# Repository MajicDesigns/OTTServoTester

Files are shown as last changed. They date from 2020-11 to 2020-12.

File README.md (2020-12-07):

# Over The Top (OTT) Servo Tester

Arduino sketch to test and calibrate micro (RC) servos.

The application can work in Manual, Sweep, Receiver Check and ESC setup modes.

## Hardware Requirements

- Arduino processor (Pro Mini, but any processor should work)
- Hitachi 1602 LCD display with IIC backpack
- Rotary encoder with built-in momentary-on switch
- Additional momentary-on switch

If you like and use this code please consider making a small donation using [PayPal](https://paypal.me/MajicDesigns/4USD)

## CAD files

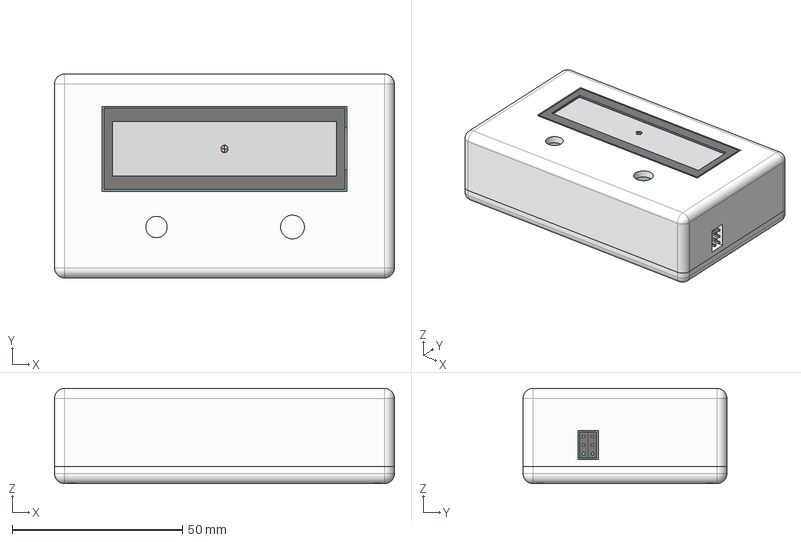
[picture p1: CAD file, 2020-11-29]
Fusion360/OTT Servo Tester Enclosure.step
100.0 x 60.0 x 28.0 mm
Cover
LCD PCB
LCD Bezel
LCD Glass
PCB Connector
I2C PCB
I2C Connectors
Cap1
Reset Body
CPU
Reset Switch
Tx
Cap2
PCB
Header
PCB (1)
Header (1)
PCB (2)

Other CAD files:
Fusion360/OTT Servo Tester Enclosure.f3z

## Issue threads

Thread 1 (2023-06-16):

OTTServoTester with LCD Keypad Shield

freetoair, 2023-06-16:
Hi Marco, I tried to modify your excellent project to work with "LCD Keypad Shield" but without success.
The part with the parallel LCD display works correctly, but the control of the analog keys is a big problem for me.
If there is some way to do it without a lot of involvement, I think it would mean a lot to many who would be happy to use this tester. If it means anything, I can upload my modified Sketch.

regards,  freetoair.

MajicDesigns, 2023-06-17:
Use the analog keys tester example in the UISwitch library to work out the analog values for the switches on your keypad shield. The substitute these values for those in the OTTtester code.

freetoair, 2023-06-17:
Yes, that's exactly what I tried to do, but as you can see from my program in debug mode when selecting in the "setup" menu, it's as if some key was pressed, but it wasn't!
Here I am sending the variant that I tried.
[OTTServoTester_LCDkeySheld.zip](https://github.com/MajicDesigns/OTTServoTester/files/11778641/OTTServoTester_LCDkeySheld.zip)

MajicDesigns, 2023-07-02:
"as you can see from my program in debug mode" - not really, I can't see anything that is debug output.

One area that often causes you problem is if you are trying to power the servos from the Arduino board. As soon as the servos start to move they will cause a dip on the voltage on the board and noise in the electonic components power supply which makes them behave erratically.

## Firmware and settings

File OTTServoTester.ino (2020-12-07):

/*
Over The Top (OTT) Servo Tester
===============================

Hardware Requirements
---------------------
* Arduino processor (Pro Mini, but any processor should work)
* Hitachi 1602 LCD display with IIC backpack
* Rotary encoder with built-in momentary-on switch
* Additional momentary-on switch

I/O Mapping - Arduino Pro Mini
------------------------------
+---+-----------------------+-------------------+
|Pin| Usage                 | Defined           |
+---+-----------------------+-------------------+
| 00| USB Serial            | N/A               |
| 01| USB Serial            | N/A               |
| 02| Servo Output A        | SERVO_PIN[0]      |
| 03| Servo Output B        | SERVO_PIN[1]      |
| 04| Servo Output C        | SERVO_PIN[2]      |
| 05| Servo Output D        | SERVO_PIN[3]      |
| 06| Servo Output E        | SERVO_PIN[4]      |
| 07| Servo Output F        | SERVO_PIN[5]      |
| 08|                       |                   |
| 09|                       |                   |
| 10|                       |                   |
| 11| Receiver Signal Pin   | RCV_PIN           |
| 12|                       |                   |
| 13|                       |                   |
| A0| Menu encoder B        | MENU_ENC_B        |
| A1| Menu encoder A        | MENU_ENC_A        |
| A2| Menu encoder select   | MENU_SEL          |
| A3| Run switch            | MENU_RUN          |
| A4| IIC SDA               | LCD_SDA           |
| A5| IID SCL               | LCD_SCL           |
| A6|                       |                   |
| A7|                       |                   |
+---+-----------------------+-------------------+

Summary
-------
The Application operates in one of three modes, cycled through a double press of the encoder switch.

Manual: Manual mode is shown by 'Man' in the top right of the display. Moving the encoder moves all
        the servos in unison. A single press of the Run switch resets all the servos to their home
        position, as configured in the associated profile.

Sweep:  Sweep mode display shows the same information as Manual mode display, with 'Swp' in the top right.
        In this mode the servos are swept between their associated profile start and end positions using
        the defined sweep profile (Linear, Sine or Square) and timing parameters. The sweep is toggled
        on/off by a single press of the Run switch.

Rcv Check: Rcv Check displays the signal characteristics from a servo controller connected to the RCV_PIN
        input. Signal high and low durations are displayed in real time.

ESC Setup: ESC (Electronic Speed Controller) setup allows the togglong of one of the outputs between high 
         and low as is normally required for ESC setup through a receiver. The ESC will be emitting tones 
         to guide you through a menu of options according to the specifics of the ESC (see appropriate ESC
         documentation). The output for the ESC can be selected by turning the rotary encoder.

The application code is configured to allow for up to MAX_SERVO servos to be attached for testing.
The actual number of active servos is set by the NUM_SERVO (<= MAX_SERVO) constant. Each of the 
Servo outputs (labeled Output A through F) is associated with a servo profile. 

Each servo has associated a profile defining the travel timing limits for the servo. Up to MAX_PROFILE
profiles are allowed for. The actual number of profiles is set by the NUM_PROFILE constant. Note the 
variable selProfile needs to be manually adjusted for menu selections if the value of NUM_PROFILE is 
changed.

The servo profiles are configurable and define the minimum and maximum values for the servo sweep 
(in microseconds), the percentage of range to set as the 'mid-point' value, the type of sweep testing 
(Linear, Sine or Square patterns), the sweep duration and the pause between sweeps. By default three 
profiles are created with range 1000 to 2000 microseconds and 'mid' point (or 'home') values at 50%, 
0% and 100% for profiles 1, 2 and 3 respectively. An output with no associated profile is considered 
as 'disabled' and will not receive control signals.

The user interface (UI) is implemented using the rotary encoder and a separate tact switch (Run switch).
In general the UI navigation operates as follows:
 * Cycle between modes by double pressing the encoder switch.
 * The Run Switch is used to run/stop execution in the mode (if applicable). A long press of the run 
   switch will immediately return the application to Manual mode.
 * The Configuration Menu only uses the encoder, accessed from Manual mode using a long press of the 
   encoder switch.
     - The top line of the display is the menu/submenu name or the value being edited.
     - Below the title, Menu Selections are displayed inside angled brackets ("<" and ">").
     - Editable values are displayed inside square brackets ("[" and "]").
     - Menu options are scrolled by turning the encoder
     - Menu options are selected by pressing the encoder switch.
     - Configuration item values are changed up/down by turning the encoder switch
     - Configuration items are confirmed by pressing the encoder switch.
     - Aborting the current menu level (menu selection or value editing) is done using a long press.
     
The application stores all its configuration information in EEPROM so that it is retained between 
processor resets. Configuration items include
* Display parameters for splash screen, menu timeouts and auto paging
* Safety limits on servo timing values
* Profile definitions (as described above)
* Assignment of profile to servo

Library Dependencies
--------------------
- Rotary encoder (MD_REncoder) at https://github.com/MajicDesigns/MD_REncoder or Arduino IDE Library Manager
- Menu switches (MD_UISwitch) at https://github.com/MajicDesigns/MD_UISwitch or Arduino IDE Library Manager
- LCD Menu (MD_Menu) at https://github.com/MajicDesigns/MD_Menu or Arduino IDE Librarey Manager
- LCD Manager (HD44780) at https://github.com/duinoWitchery/hd44780 or Arduino IDE Library Manager

Version History
---------------
Dec 2020 v1.1.0
- Added ESC setup mode

Nov 2020 v1.0.0
- First Release

Copyright and Licensing
-----------------------
Copyright (C) 2020 Marco Colli. All rights reserved.

This is free software; you can redistribute it and/or
modify it under the terms of the GNU Lesser General Public
License as published by the Free Software Foundation; either
version 2.1 of the License, or (at your option) any later version.

This library is distributed in the hope that it will be useful,
but WITHOUT ANY WARRANTY; without even the implied warranty of
MERCHANTABILITY or FITNESS FOR A PARTICULAR PURPOSE. See the GNU
Lesser General Public License for more details.

You should have received a copy of the GNU Lesser General Public
License along with this software; if not, write to the Free Software
Foundation, Inc., 51 Franklin St, Fifth Floor, Boston, MA 02110-1301 USA
*/
#include <EEPROM.h>
#include <Servo.h>

#include <Wire.h>
#include <hd44780.h>
#include <hd44780ioClass/hd44780_I2Cexp.h>

#include <MD_REncoder.h>
#include <MD_UISwitch.h>
#include <MD_Menu.h>

// Application options
const uint8_t MAX_SERVO = 6;   // Maximum number of servos allowed for. NUM_SERVO sets the actual number (below).

#define DEBUG   0  // enable debugging output
#define USE_RCV 1  // enable the Receiver functionality
#define USE_ESC 1  // enable the ESC setup functionality

#if DEBUG
#define PRINT(s, n)  do { Serial.print(F(s)); Serial.print(n); } while (false);
#define PRINTS(s)    do { Serial.print(F(s)); } while (false);
#define PRINTX(s, x)  do { Serial.print(F(s)); Serial.print(F("x")); Serial.print(x, HEX); }  while (false);
#else
#define PRINT(s, n)
#define PRINTS(s)
#define PRINTX(s, x)
#endif // DEBUG

//----------------------------------------------------------
// Miscellaneous definitions/variables
#define APP_NAME "OTT Servo Tester"
#define APP_VER  "v1.1.0"

typedef const char PROGMEM message_t;	// pointer to flash memory string

enum:uint8_t 
{ 
  RUN_MANUAL_INIT, RUN_MANUAL,
  RUN_SWEEP_INIT, RUN_SWEEP_WAITING, RUN_SWEEP,
  RUN_RCHECK_INIT, RUN_RCHECK, RUN_RCHECK_PAUSE,
  RUN_ESC_INIT, RUN_ESC,
  RUN_MENU_INIT, RUN_MENU
} runMode = RUN_MANUAL_INIT;
bool dataChanged = true;    // flag for new data to display

//----------------------------------------------------------
// Servo Hardware
const uint16_t SERVO_UPDATE_FREQ = 50;       // standard servo update frequency in Hz
const uint16_t SERVO_LOWER_HARDLIMIT = 500;  // servo abs lower hard limit
const uint16_t SERVO_UPPER_HARDLIMIT = 2500; // servo abs upper hard limit

const uint8_t NUM_SERVO = MAX_SERVO;         // number of physical servos (can be [1..MAX_SERVO-1])
const uint8_t SERVO_PIN[MAX_SERVO] = { 2, 3, 4, 5, 6, 7 };  // only NUM_SERVO pins are relevant

const uint8_t NUM_PROFILE = 3;       // number of available profiles - also adjust selProfile below
message_t selProfile[] = "-|1|2|3";  // menu selection data for profile - adjust to allow NUM_PROFILE selections

message_t selSweepType[] = "Lin|Sin|Sqr";  // menu selection data - for sweep type in profile
const uint8_t SWP_LINEAR = 0;   // index 0
const uint8_t SWP_SINE = 1;     // index 1
const uint8_t SWP_SQUARE = 2;   // index 2

Servo servo[NUM_SERVO];

//----------------------------------------------------------
// Receiver Signal Test
#if USE_RCV
const uint8_t RCV_PIN = 11;
const uint32_t RCV_PAUSE_TIME = 500; // milliseconds pause between readings

struct
{
  uint32_t timeSig;  // signal duration measured (microseconds)
  uint32_t timeGap;  // space duration measured (microseconds)
  uint32_t timePause;    // receiver pause timer counter (milliseconds)
} rcvCheckData;
#endif

//----------------------------------------------------------
// ESC Setup
#if USE_ESC
uint8_t escOutput;     // output used for ESC setup
bool    escState;      // currently high or low
#endif

//----------------------------------------------------------
// Menu Rotary Encoder Interface I/O
const uint8_t MENU_SEL = A2;   // Selection switch on encoder
const uint8_t MENU_RUN = A3;   // Run start/stop
const uint8_t MENU_ENC_A = A1; // Encode Channel A
const uint8_t MENU_ENC_B = A0; // Encoder Channel B

MD_REncoder encMenu(MENU_ENC_A, MENU_ENC_B);
MD_UISwitch_Digital swMenuSel(MENU_SEL);
MD_UISwitch_Digital swMenuRun(MENU_RUN);
uint8_t displayPageBase = 0;   // base index for servo disaply page

//----------------------------------------------------------
// LCD Display definitions (2 wire display interface)
#define LCD_PRINT(c, r, s) do { lcd.setCursor(c,r); lcd.print(s); } while (false);
#define LCD_WRITE(c, r, s) do { lcd.setCursor(c,r); lcd.write(s); } while (false);

const uint8_t LCD_ROWS = 2;
const uint8_t LCD_COLS = 16;

const uint8_t LCD_SCL = A5;
const uint8_t LCD_SDA = A4;

hd44780_I2Cexp lcd;

//----------------------------------------------------------
// Auto paging management definitions
const uint32_t PAGE_TIME = 2000;   // page displayed time in ms for auto paging
uint32_t timerPage;     // keeping track of millis() time

//----------------------------------------------------------
// Configuration Information handling
//
// - Config info is made up of common data and additional data per channel.
// - This config info is saved at the start of EEPROM memory (address EEPROM_ADDR).
//
// Any changes to data structure need to be reflected in the static initializers in 
// the reset() method.
//
class cAppConfig
{
public:
  // Data fields --------------------------------
  struct
  {
    uint8_t signature[2];

    // UI options
    uint8_t		tmMenu;			// menu timeout in seconds
    uint8_t		tmSplash;		// splash screen display time in seconds
    bool      autoPage;   // automatically page through the main display

    // Safety limits for signal setting
    uint16_t  limLow;     // low limit in milliseconds
    uint16_t  limHigh;    // high limit in milliseconds

    // Servo Signal options
    struct 
    {
      bool enabled;       // true if servo is enabled for output
      uint8_t profileId;  // configured profile to use
    } servo[MAX_SERVO];
    
    // Profile information
    struct 
    {
      uint16_t low;        // setting for 0% of range
      uint16_t high;       // setting for 100% of range
      uint8_t  home;       // setting for home position as percentage
      uint8_t  sweepType;  // sweep type
      uint16_t sweepTime;  // duration in milliseconds for one low->high or high->low sweep
      uint16_t sweepPause; // pause between sweep movements in milliseconds
    } profile[NUM_PROFILE];

  } data;

  // Methods ------------------------------------
  cAppConfig(uint16_t eepromBase = 0) : _eepromBase(eepromBase) {}

  void reset(void)
  {
    PRINTS("\nConfig Reset");

    data.signature[0] = EEPROM_SIG[0];
    data.signature[1] = EEPROM_SIG[1];

    // Global config presets 
    data.tmMenu = 4;      // menu timeout in seconds
    data.tmSplash = 2;    // slapsh screen timeout in seconds

    // Safety limits 
    data.limLow = SERVO_LOWER_HARDLIMIT;    // low limit in microseconds
    data.limHigh = SERVO_UPPER_HARDLIMIT;   // high limit in microseconds
    data.autoPage = true;                   // default to autopaging

    // Servo information
    for (uint8_t i = 0; i < MAX_SERVO; i++)
    {
      data.servo[i].enabled = true;
      data.servo[i].profileId = 0;    // all use the same profile initially
    }

    // Profiles information
    for (uint8_t i = 0; i < NUM_PROFILE; i++)
    {
      data.profile[i].low = 1000;   // in microseconds
      data.profile[i].high = 2000;  // in microseconds
      data.profile[i].home = 0;     // percentage of range
      data.profile[i].sweepType = SWP_LINEAR; // one of the 
      data.profile[i].sweepTime = 2000;  // in milliseconds
      data.profile[i].sweepPause = 200;  // in milliseconds
    }
    data.profile[0].home = 50;    // set specific percentage value
    data.profile[1].home = 0;
    data.profile[2].home = 100;
  }

  void begin(void)
  {
    if (!load())
    {
      reset();
      save();
    }
  }

  void save(void) 
  { 
    PRINTS("\nConfig Save");
    EEPROM.put(_eepromBase, data);
  }
  
  bool load(void) 
  {
    PRINTS("\nConfig Load");

    EEPROM.get(_eepromBase, data);

    if (data.signature[0] != EEPROM_SIG[0] || data.signature[1] != EEPROM_SIG[1])
      return(false);

    return(true);
  }

protected:
  const uint16_t EEPROM_ADDR = 0;
  const uint8_t EEPROM_SIG[2] = { 0x11, 0xee };

  uint16_t  _eepromBase;
};

cAppConfig C;

// --------------------------------------------------------
// Servo real-time management data
struct
{
  uint16_t curV, setV;   // current and setpoit value setting
  uint32_t timeStart;    // sweep start in microseconds
  uint16_t timeDelta;    // in microseconds
  int8_t   deltaPct;     // percentage increment +/-
  int16_t  sweepPct;     // Current percentage through
  uint8_t  state;        // Current sweep ruinning state
} servoData[NUM_SERVO];

// ---------------------------------------------------------
// Miscellaneous functions
void setServoSPPct(uint8_t s, uint8_t pct)
{
  // sanity checks
  if (s >= NUM_SERVO) return;
  if (pct > 100) pct = 100;

  // do the deed
  uint8_t id = C.data.servo[s].profileId;
  uint32_t offset = C.data.profile[id].high - C.data.profile[id].low;

  offset = (offset * pct) / 100L;
  //PRINT("\nPct ", pct);
  //PRINT(" range ", C.data.profile[id].high - C.data.profile[id].low);
  //PRINT(" = set Offset ", offset);
  servoData[s].setV = C.data.profile[id].low + offset;
}

void setAllServoHome(void)
{
  for (uint8_t i = 0; i < NUM_SERVO; i++)
    if (C.data.servo[i].enabled)
      setServoSPPct(i, C.data.profile[C.data.servo[i].profileId].home);
}

void doServoSweep(uint8_t s, bool restart = false)
{
  if (restart)
  {
    servoData[s].state = 0;
    return;
  }

  uint8_t id = C.data.servo[s].profileId;

  switch (servoData[s].state)
  {
  case 0: // IDLE
    switch (C.data.profile[id].sweepType)
    {
    case SWP_LINEAR:
    case SWP_SINE:
      servoData[s].timeDelta = 1000 / SERVO_UPDATE_FREQ;
      servoData[s].deltaPct = (100 * servoData[s].timeDelta) / C.data.profile[id].sweepTime;
      break;

    case SWP_SQUARE:
      servoData[s].timeDelta = C.data.profile[id].sweepTime;
      servoData[s].deltaPct = 100;
      break;

    }
    //PRINT("\n[", s);
    //PRINT("] Time Delta ", servoData[s].timeDelta);
    //PRINT(" Delta Pct ", servoData[s].deltaPct);
    servoData[s].timeStart = 0;   // force the first update
    servoData[s].state = 1;       // start sweeping
    break;
    
  case 1: // SWEEPING
    if (millis() - servoData[s].timeStart >= servoData[s].timeDelta)
    {
      // now one deltaPCT advanced in the sweep
      servoData[s].sweepPct += servoData[s].deltaPct;
      //PRINT("\n[", s);
      //PRINT("] Current % ", servoData[s].sweepPct);
      if (servoData[s].sweepPct > 100) servoData[s].sweepPct = 100;
      if (servoData[s].sweepPct < 0) servoData[s].sweepPct = 0;
      //PRINT(" adjusted to % ", servoData[s].sweepPct);

      // Work out the servo setpoint value setting based on pct through and type of sweep
      switch (C.data.profile[C.data.servo[s].profileId].sweepType)
      {
      case SWP_LINEAR:
      case SWP_SQUARE:
        setServoSPPct(s, servoData[s].sweepPct);
        break;

      case SWP_SINE:
        servoData[s].setV = C.data.profile[id].low;
        servoData[s].setV += sin((PI * servoData[s].sweepPct) / 100) * (C.data.profile[id].high - C.data.profile[id].low);
        //PRINT("\nSINE: Current V ", servoData[s].setV);
        break;
      }

      // reached the end of the sweep?
      if ((servoData[s].sweepPct >= 100 && servoData[s].deltaPct > 0) ||
          (servoData[s].sweepPct == 0 && servoData[s].deltaPct < 0))
      {
        PRINT("\n[", s);
        PRINTS("] SWEEP COMPLETE");
        servoData[s].state = 2;    // time to wait for the pause time between sweeps
        servoData[s].deltaPct = -servoData[s].deltaPct;   // reverse direction next run
        servoData[s].timeStart = millis();
      }
      else
      {
        // next time to do something in this state
        servoData[s].timeStart = servoData[s].timeStart + servoData[s].timeDelta;
      }
    }
    break;
    
  case 2:  // PAUSING
    if (millis() - servoData[s].timeStart >= C.data.profile[id].sweepPause)
    {
      PRINT("\n[", s);
      PRINTS("] PAUSE COMPLETE");
      servoData[s].state = 1;
      servoData[s].timeStart = millis();
    }
    break;
  }
}

void nextPage(void)
// set up the display to be for the next page
{
  displayPageBase += LCD_ROWS;
  if (displayPageBase >= NUM_SERVO)
    displayPageBase = 0;      // roll over to start
  // PRINT("Display Base = ", displayPageBase);
  dataChanged = true;
}

//----------------------------------------------------------
// Menu handling data and functions prototypes
MD_Menu::value_t vBuf;        // interface buffer for value editing
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
void loop(void) 
{
  // check if the servo needs to be moved
  for (uint8_t i = 0; i < NUM_SERVO; i++)
  {
    if (servoData[i].curV != servoData[i].setV)
    {
      servo[i].writeMicroseconds(servoData[i].setV);
      servoData[i].curV = servoData[i].setV;
      dataChanged = true;
    }
  }

  // do any display updates?
  if (C.data.autoPage && millis() - timerPage >= PAGE_TIME)
  {
    PRINTS("\nPAGING");
    nextPage();
    timerPage = millis();
  }
  if (!M.runMenu()) 
    displayRefresh();

  // now check if we need to process anything else 
  // based on the current run mode
  switch (runMode)
  {
    // MANUAL mode --------------------------------
    case RUN_MANUAL_INIT:
      dataChanged = true;
      runMode = RUN_MANUAL;
      break;

    case RUN_MANUAL:
      encoderMenuUI();
      break;

    // SWEEP mode ---------------------------------
    case RUN_SWEEP_INIT:
      PRINTS("\n> SWEEP INIT");
      for (uint8_t i = 0; i < NUM_SERVO; i++)
        if (C.data.servo[i].enabled) doServoSweep(i, true);
      runMode = RUN_SWEEP_WAITING;
      PRINTS(" -> SWEEP WAIT");
      break;

    case RUN_SWEEP_WAITING:
      encoderMenuUI();
      break;

    case RUN_SWEEP:
      //PRINTS("\nSWEEP RUN");
      for (uint8_t i = 0; i < NUM_SERVO; i++)
        if (C.data.servo[i].enabled) doServoSweep(i);
      encoderMenuUI();
      break;

    // RECEIVER CHECK mode ----------------------
    case RUN_RCHECK_INIT:
      PRINTS("\n> RCHECK INIT");
#if USE_RCV
      rcvCheckData.timeSig = rcvCheckData.timeGap = 0;
      runMode = RUN_RCHECK;
#else
      runMode = RUN_ESC_INIT;
#endif
      break;

#if USE_RCV
    case RUN_RCHECK:
      rcvCheckData.timeSig = pulseIn(RCV_PIN, HIGH, 100000UL);
      rcvCheckData.timeGap = pulseIn(RCV_PIN,  LOW, 100000UL);
      dataChanged = true;
      rcvCheckData.timePause = millis();
      runMode = RUN_RCHECK_PAUSE;
      break;

    case RUN_RCHECK_PAUSE:
      if (millis() - rcvCheckData.timePause >= RCV_PAUSE_TIME)
        runMode = RUN_RCHECK;
      encoderMenuUI();
      break;
#endif

    // ESC mode ---------------------------------
    case RUN_ESC_INIT:
      PRINTS("\n> ESC INIT");
#if USE_ESC
      escState = true;    // always start sequence with this HIGH
      runMode = RUN_ESC;
#else
      runMode = RUN_MANUAL_INIT;
#endif
      break;

#if USE_ESC
    case RUN_ESC:
      encoderMenuUI();
      if (C.data.servo[escOutput].enabled)
        setServoSPPct(escOutput, escState ? 100 : 0);
      break;
#endif

    // MENU mode --------------------------------
    case RUN_MENU_INIT:
      menuDisplay(MD_Menu::DISP_CLEAR, nullptr);
      M.runMenu(true);   // force running the menu
      runMode = RUN_MENU;
      break;

    case RUN_MENU:
      if (!M.runMenu())
      {
        M.setTimeout(C.data.tmMenu * 1000);	// in case we have changed the timeout value
        runMode = RUN_MANUAL_INIT;
      }
      break;

    default:
      runMode = RUN_MANUAL_INIT;
      break;
  }
}

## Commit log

2020-11-29 Added 3D enclosure model files
    [OTT Servo Tester Enclosure.f3z, OTT Servo Tester Enclosure.step]
2020-12-07 Added ESC Setup mode
